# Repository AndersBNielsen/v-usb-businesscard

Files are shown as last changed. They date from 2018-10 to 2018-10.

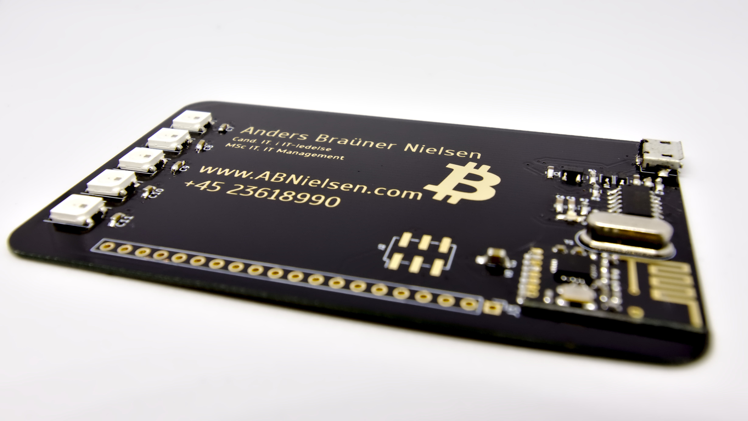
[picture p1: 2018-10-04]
abnielsen-bcard.jpg

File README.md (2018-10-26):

# ATTiny84 V-USB Business card

Read the full description here: https://abnielsen.com/2018/10/02/business-card-rf24-ws2812b-attiny84-usb/

This project contains KiCad schematics and board layouts, modified versions of the RF24 nRF24L01+ library (https://github.com/nRF24/RF24) and Adafruit's TrinketHidCombo library (https://github.com/adafruit/Adafruit-Trinket-USB/tree/master/TrinketHidCombo) to work with the ATTiny84 with a 16mhz crystal. 

The TrinketHidCombo needed to be reconfigured for the different registers on the T84 compared to the T85 and the RF24 library needed to be made compatible with clockwise pin definitions(a la damellis core).

The microusb connector footprint used is a modified version of one found in Sparkfun's KiCAD connector library. Thanks! (https://github.com/sparkfun/SparkFun-KiCad-Libraries) 

## So what does it do?
It's my business card. It also doubles as a development board. It successfully fits code to accept commands wirelessly to control onboard(or external) WS2812B LEDs and send Play/Pause/Vol up/Vol down/Stop media keys via USB, into the 8192 bytes available on an ATTiny84. Hardware for sending the RF commands is not covered by this project. 

Update: It now also works as a USBasp programmer! (https://github.com/AndersBNielsen/USBasp-t)

My business card

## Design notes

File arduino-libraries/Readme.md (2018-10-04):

This folder contains the Arduino libraries used(if modified for this project).

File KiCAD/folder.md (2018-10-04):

This folder contains schematics and board layout for KiCAD (v4)
..and a Bitcoin logo

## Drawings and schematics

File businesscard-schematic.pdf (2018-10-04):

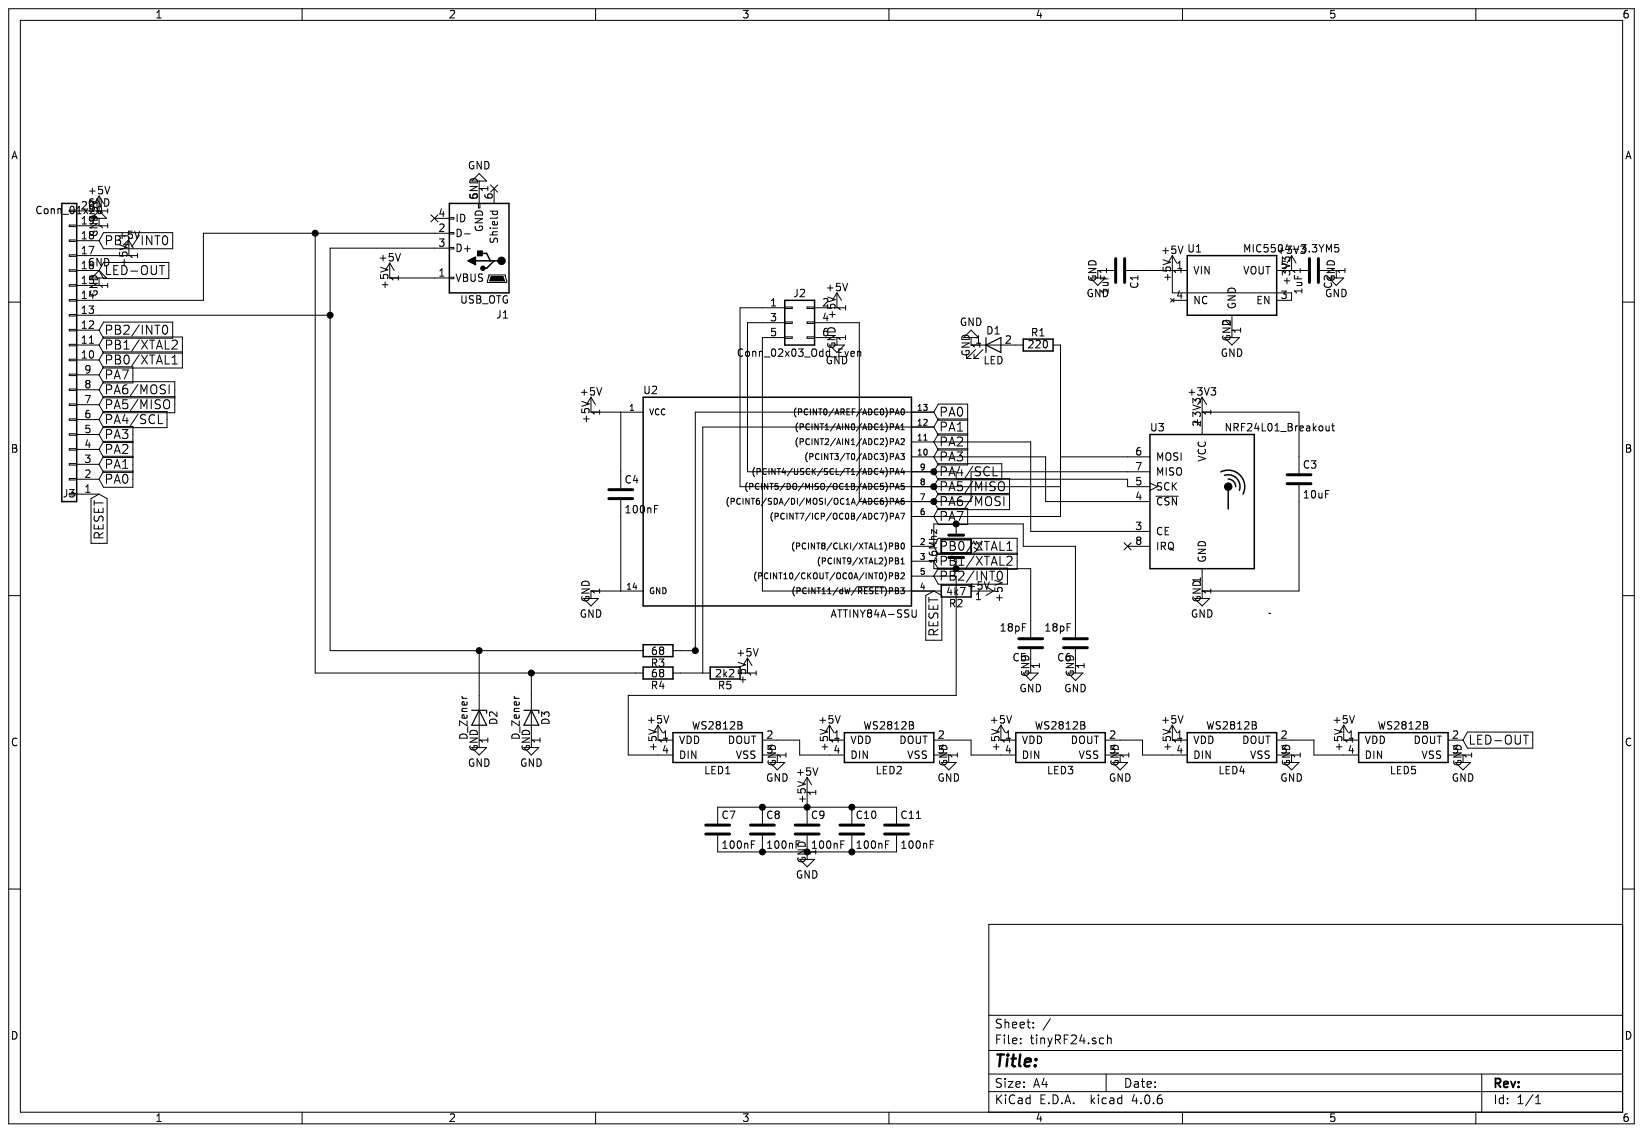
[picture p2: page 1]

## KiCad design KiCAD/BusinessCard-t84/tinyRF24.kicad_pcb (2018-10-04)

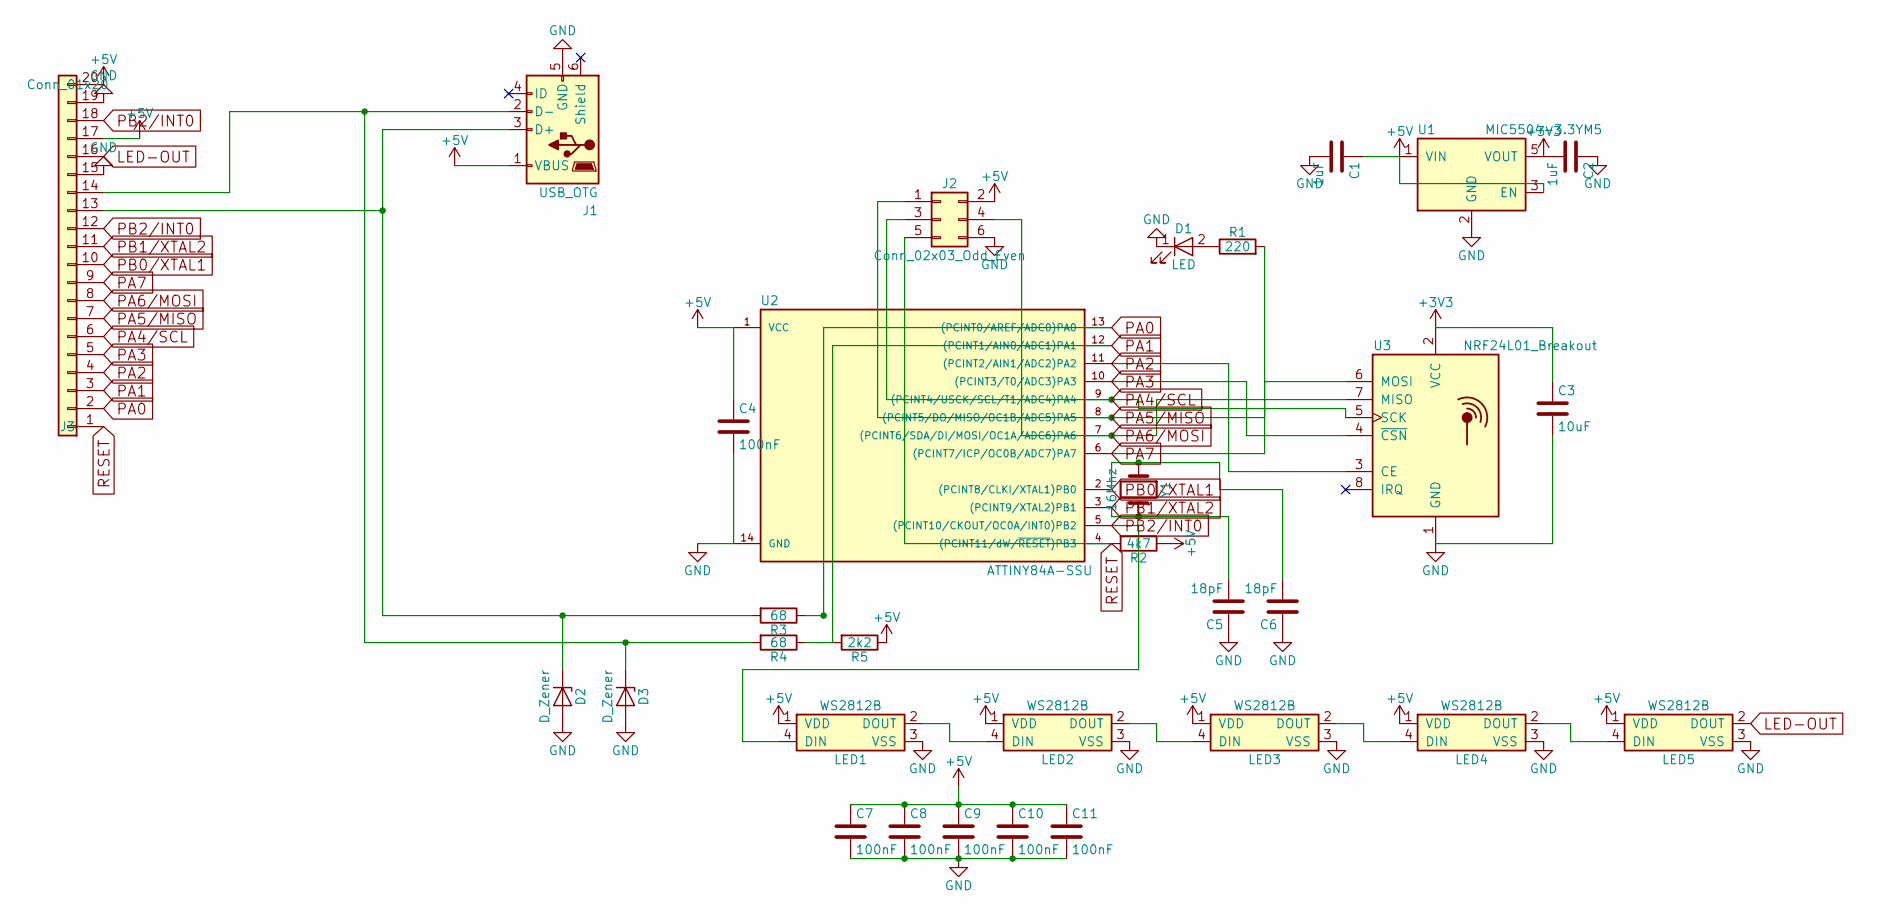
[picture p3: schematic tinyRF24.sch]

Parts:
C1, C2: 1uF; C_0603_HandSoldering
C3: 10uF; C_0805_HandSoldering
C4, C7, C8, C9, C10, C11: 100nF; C_0603_HandSoldering
C5, C6: 18pF; C_0603_HandSoldering
D1: LED; LED_0603_HandSoldering
D2, D3: D_Zener; D_SOD-323
J1: USB_OTG; USB-B-MICRO-SMD_V03-fixed
J2: Conn_02x03_Odd_Even; Pin_Header_Straight_2x03_Pitch2.54mm_SMD
J3: Conn_01x20; Pin_Header_Straight_1x20_Pitch2.54mm
LED1, LED2, LED3, LED4, LED5: WS2812B; LED_WS2812B-PLCC4
R1: 220; R_0603_HandSoldering
R2: 4k7; R_0603_HandSoldering
R3, R4: 68; R_0603_HandSoldering
R5: 2k2; R_0603_HandSoldering
U1: MIC5504-3.3YM5; SOT-23-5
U2: ATTINY84A-SSU; SOIC-14_3.9x8.7mm_Pitch1.27mm
U3: NRF24L01_Breakout; NRF24L01-SMD
Y1: 16Mhz; Crystal_HC49-4H_Vertical

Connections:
+3V3: C2.2, C3.1, U1.5 (VOUT), U3.2 (VCC)
+5V: C1.1, C4.1, C7.1, C8.1, C9.1, C10.1, C11.1, J1.1 (VBUS), J2.2, J3.17, J3.20, LED1.1 (VDD), LED2.1 (VDD), LED3.1 (VDD), LED4.1 (VDD), LED5.1 (VDD), R2.1, R5.1, U1.1 (VIN), U1.3 (EN), U2.1 (VCC)
GND: C1.2, C2.1, C3.2, C4.2, C5.1, C6.1, C7.2, C8.2, C9.2, C10.2, C11.2, D1.1 (K), D2.2 (A), D3.2 (A), J1.5 (GND), J2.6, J3.15, J3.19, LED1.3 (VSS), LED2.3 (VSS), LED3.3 (VSS), LED4.3 (VSS), LED5.3 (VSS), U1.2 (GND), U2.14 (GND), U3.1 (GND)
LED-OUT: J3.16, LED5.2 (DOUT)
unnamed: D1.2 (A), R1.1
unnamed: D2.1 (K), J1.3 (D+), J3.13, R3.2
unnamed: D3.1 (K), J1.2 (D-), J3.14, R4.2
unnamed: LED1.2 (DOUT), LED2.4 (DIN)
unnamed: LED2.2 (DOUT), LED3.4 (DIN)
unnamed: LED3.2 (DOUT), LED4.4 (DIN)
unnamed: LED4.2 (DOUT), LED5.4 (DIN)
PA0: J3.2, R3.1, U2.13 ((PCINT0/AREF/ADC0)PA0)
PA1: J3.3, R4.1, R5.2, U2.12 ((PCINT1/AIN0/ADC1)PA1)
PA2: J3.4, U2.11 ((PCINT2/AIN1/ADC2)PA2), U3.3 (CE)
PA3: J3.5, U2.10 ((PCINT3/T0/ADC3)PA3), U3.4 (~CSN)
PA4/SCL: J2.3, J3.6, U2.9 ((PCINT4/USCK/SCL/T1/ADC4)PA4), U3.5 (SCK)
PA5/MISO: J2.1, J3.7, U2.8 ((PCINT5/DO/MISO/OC1B/ADC5)PA5), U3.6 (MOSI)
PA6/MOSI: J2.4, J3.8, U2.7 ((PCINT6/SDA/DI/MOSI/OC1A/ADC6)PA6), U3.7 (MISO)
PA7: J3.9, R1.2, U2.6 ((PCINT7/ICP/OC0B/ADC7)PA7)
PB0/XTAL1: C6.2, J3.10, U2.2 ((PCINT8/CLKI/XTAL1)PB0), Y1.1
PB1/XTAL2: C5.2, J3.11, U2.3 ((PCINT9/XTAL2)PB1), Y1.2
PB2/INT0: J3.12, J3.18, LED1.4 (DIN), U2.5 ((PCINT10/CKOUT/OC0A/INT0)PB2)
RESET: J2.5, J3.1, R2.2, U2.4 ((PCINT11/dW/~RESET~)PB3)

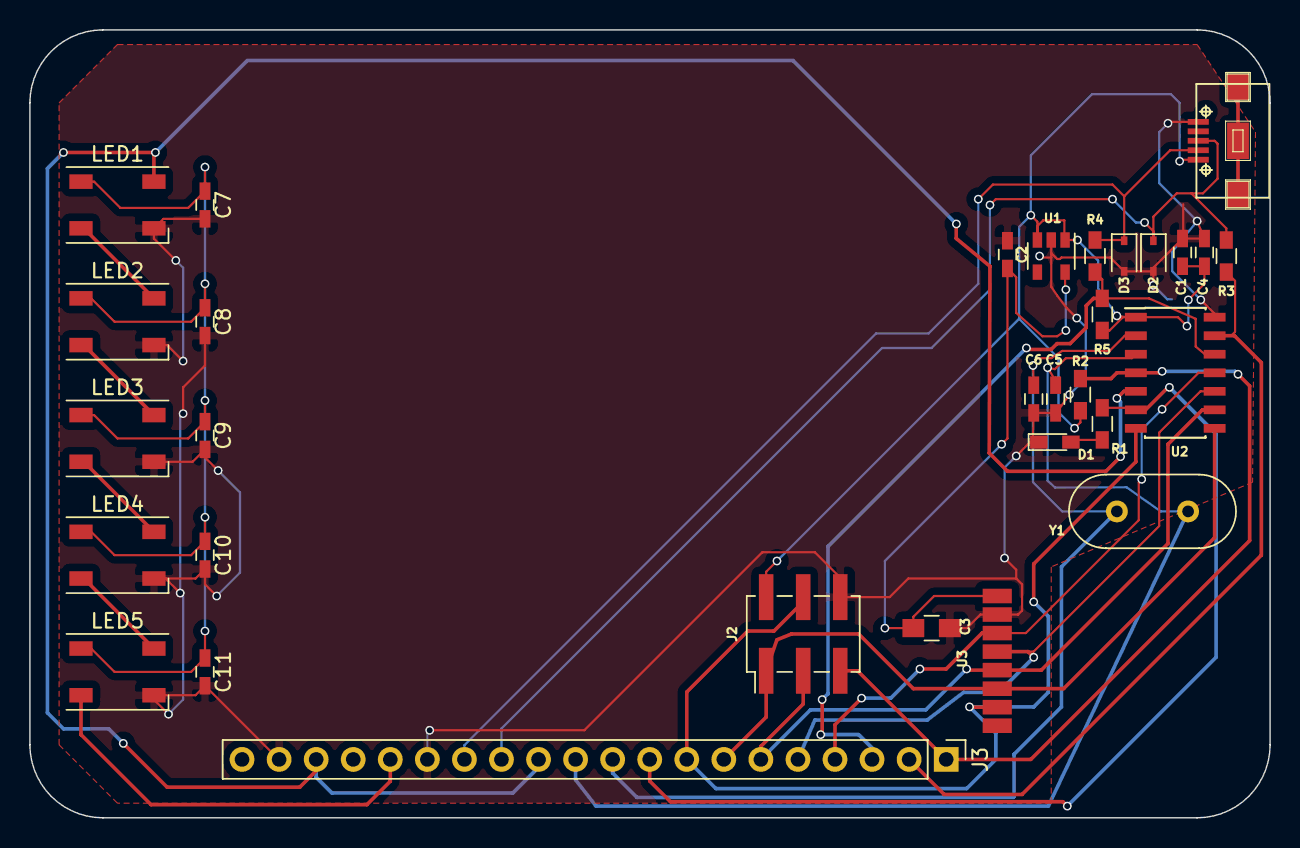
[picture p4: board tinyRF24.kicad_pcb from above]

Board: 2 copper layers, 85.0 x 54.0 mm, 31 parts (0 on the bottom side), 23 nets.

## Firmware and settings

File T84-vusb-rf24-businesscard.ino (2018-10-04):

#include <RF24.h> //My fork with a fix for ATTiny44/84
#include <avr/wdt.h>
#include <avr/interrupt.h>
#include <Adafruit_NeoPixel.h>
#ifdef __AVR__
  #include <avr/power.h>
#endif

#define BIT(x) (0x01 << (x)) 
#define getBit(p,m) ((p) & BIT((m)))

#include <TrinketHidCombo.h> //My fork for ATTiny44/84

#define PIN 8
Adafruit_NeoPixel strip = Adafruit_NeoPixel(5, PIN, NEO_GRB + NEO_KHZ800);

#define LED_BUILTIN 7

uint8_t ledState = HIGH; //Status LED
unsigned long previousMillis = 0;
unsigned int freq = 1000; //LED blinking frequency
uint8_t mode = 1;
uint8_t isConnected;

//uint64_t pipe01 = 0xFAFBFCFDFELL;
uint64_t pipe02 = 0xFAFAFAFA02LL;
RF24 radio(2, 3);

typedef struct{
  byte mode;
  byte data;
  uint64_t address;
}
message;

message msg; 

void setup() {

pinMode(LED_BUILTIN, OUTPUT);
 
TrinketHidCombo.begin();
while (getBit(PORTA,7) == 0 && millis() < 2000) { //I hackish-ly set A7 high in usbdrv.c / usbDeviceRead(), since TrinkedHidCombo.isConnected() doesnt work for some reason.
stayAliveDelay(0);
}
if (millis() < 1999) { //If under 2 sec then we have USB.
  isConnected = 1;
  mode = 3; 
}

strip.begin();
//  strip.show(); // Initialize all pixels to 'off' //Scraping a few bytes
    
  radio.begin();
   radio.setPayloadSize(sizeof(msg));
   
//Error out if radio not detected 
#ifdef debug 
  if (!radio.isPVariant()) { //Easy way to detect if tranceiver correctly connected
  while (1) {
    digitalWrite(LED_BUILTIN, HIGH);
    delay(50);
    digitalWrite(LED_BUILTIN, LOW);
    delay(50);
  }
}
#endif

//Send out address for any remote to pick up when first powered on
#ifdef debug
 radio.stopListening();
  radio.setPayloadSize(sizeof(msg));
  radio.openWritingPipe(pipe01);
  msg.address = pipe02;
  msg.data = 100;
  msg.mode = 100;
bool ok = radio.write(&msg, sizeof(msg)); 
#endif
//Maybe do something if successfully sent.


//  radio.openReadingPipe(0, pipe01);
  radio.openReadingPipe(1, pipe02);
  radio.startListening();

  wdt_enable(WDTO_2S);// enable 2s watchdog timer
  WDTCSR &= ~(1<<WDE);
  WDTCSR |= (1<<WDIE);
    wdt_reset();
}

void loop() {
uint8_t pipe;
stayAliveDelay(0);

 if (radio.available(&pipe)) //Msg available?
  {
     while (radio.available()) {     
       radio.read(&msg, sizeof(msg)); //Get message
     }
  
//Parse message
    switch (msg.data) {
        case 1:
        mode = 1;
        if (isConnected) TrinketHidCombo.pressMultimediaKey(MMKEY_PLAYPAUSE);
        break;
        case 2:
        mode = 2;
        if (isConnected) TrinketHidCombo.pressMultimediaKey(MMKEY_VOL_UP);
        break;
        case 3:
        mode = 3;
        if (isConnected) TrinketHidCombo.pressMultimediaKey(MMKEY_VOL_DOWN);
        break;
        case 4:
        mode = 4;
        if (isConnected) TrinketHidCombo.pressMultimediaKey(MMKEY_STOP);
        break;
        default:
       freq = 0;
 break;
    }
  }
switch (mode) {
              
        case 1:
        rainbow(10);        
        break;
        case 2:
        rainbowCycle(10);
        break;
        case 3:
        //Set to princess's color
        for(int i=0; i<strip.numPixels(); i++) {
          if (radio.available()) break;
        strip.setPixelColor(i, 255,0,255);
        }
        break;
        case 4:
        //Off
        for(int i=0; i<strip.numPixels(); i++) {        
        strip.setPixelColor(i, 0,0,0);
        if (radio.available()) break;
        freq = 0;
        }  
        default:
       freq = 0;
 break;
    }
    strip.show();
//Non-blocking blinking
  if (millis() - previousMillis >= freq) {
    // save the last time you blinked the LED
    previousMillis = millis();

    // if the LED is off turn it on and vice-versa:
      if (ledState == LOW && freq > 0) {
        ledState = HIGH;
      } else {
        ledState = LOW;
      }
    // set the LED with the ledState of the variable:
    digitalWrite(LED_BUILTIN, ledState);
  }


}

// Fill the dots one after the other with a color
void colorWipe(uint32_t c, uint8_t wait) {
  for(uint16_t i=0; i<strip.numPixels(); i++) {
    if (radio.available()) break;
    strip.setPixelColor(i, c);
    strip.show();
    stayAliveDelay(wait);
  }
}

void rainbow(uint8_t wait) {
  uint16_t i, j;

  for(j=0; j<256; j++) {
    if (radio.available()) break;
    for(i=0; i<strip.numPixels(); i++) {
      if (radio.available()) break;
      strip.setPixelColor(i, Wheel((i+j) & 255));
    }
    strip.show();
    stayAliveDelay(wait);
  }
}

// Slightly different, this makes the rainbow equally distributed throughout
void rainbowCycle(uint8_t wait) {
  uint16_t i, j;

  for(j=0; j<256*5; j++) { // 5 cycles of all colors on wheel
    if (radio.available()) break;
    for(i=0; i< strip.numPixels(); i++) {
      if (radio.available()) break;
      strip.setPixelColor(i, Wheel(((i * 256 / strip.numPixels()) + j) & 255));
    }
    strip.show();
    stayAliveDelay(wait);
  }
}

// Input a value 0 to 255 to get a color value.
// The colours are a transition r - g - b - back to r.
uint32_t Wheel(byte WheelPos) {
  WheelPos = 255 - WheelPos;
  if(WheelPos < 85) {
    return strip.Color(255 - WheelPos * 3, 0, WheelPos * 3);
  }
  if(WheelPos < 170) {
    WheelPos -= 85;
    return strip.Color(0, WheelPos * 3, 255 - WheelPos * 3);
  }
  WheelPos -= 170;
  return strip.Color(WheelPos * 3, 255 - WheelPos * 3, 0);
}

void stayAliveDelay (long datime) {
  TrinketHidCombo.poll();
    wdt_reset();
  long starttime = millis();
  while (millis() - starttime < datime) {
    TrinketHidCombo.poll();
    wdt_reset();
  }
}

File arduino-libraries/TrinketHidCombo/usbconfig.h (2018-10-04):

/* Name: usbconfig.h
 * Project: V-USB, virtual USB port for Atmel's(r) AVR(r) microcontrollers
 * Author: Christian Starkjohann
 * Creation Date: 2005-04-01
 * Tabsize: 4
 * Copyright: (c) 2005 by OBJECTIVE DEVELOPMENT Software GmbH
 * License: GNU GPL v2 (see License.txt), GNU GPL v3 or proprietary (CommercialLicense.txt)
 */

/*
This file has been modified for use as a part of TrinketHidCombo

Copyright (c) 2013 Adafruit Industries
All rights reserved.

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
You should have received a copy of the GNU Lesser General Public
License along with TrinketHidCombo. If not, see
<http://www.gnu.org/licenses/>.
*/

#include "cmdline_defs.h"

#ifndef __usbconfig_h_included__
#define __usbconfig_h_included__

/* ---------------------------- Hardware Config ---------------------------- */

#if defined (__AVR_ATtiny44__) || defined (__AVR_ATtiny84__)
#define USB_CFG_IOPORTNAME      A
#define USB_CFG_DMINUS_BIT      1
#define USB_CFG_DPLUS_BIT       0
#endif
//#define USB_CFG_IOPORTNAME      B
/* This is the port where the USB bus is connected. When you configure it to
 * "B", the registers PORTB, PINB and DDRB will be used.
 */
//#define USB_CFG_DMINUS_BIT      3
/* This is the bit number in USB_CFG_IOPORT where the USB D- line is connected.
 * This may be any bit in the port.
 */
//#define USB_CFG_DPLUS_BIT       4
/* This is the bit number in USB_CFG_IOPORT where the USB D+ line is connected.
 * This may be any bit in the port. Please note that D+ must also be connected
 * to interrupt pin INT0! [You can also use other interrupts, see section
 * "Optional MCU Description" below, or you can connect D- to the interrupt, as
 * it is required if you use the USB_COUNT_SOF feature. If you use D- for the
 * interrupt, the USB interrupt will also be triggered at Start-Of-Frame
 * markers every millisecond.]
 */
#define USB_CFG_CLOCK_KHZ       (F_CPU/1000)
/* Clock rate of the AVR in kHz. Legal values are 12000, 12800, 15000, 16000,
 * 16500, 18000 and 20000. The 12.8 MHz and 16.5 MHz versions of the code
 * require no crystal, they tolerate +/- 1% deviation from the nominal
 * frequency. All other rates require a precision of 2000 ppm and thus a
 * crystal!
 * Since F_CPU should be defined to your actual clock rate anyway, you should
 * not need to modify this setting.
 */
#define USB_CFG_CHECK_CRC       0
/* Define this to 1 if you want that the driver checks integrity of incoming
 * data packets (CRC checks). CRC checks cost quite a bit of code size and are
 * currently only available for 18 MHz crystal clock. You must choose
 * USB_CFG_CLOCK_KHZ = 18000 if you enable this option.
 */

/* ----------------------- Optional Hardware Config ------------------------ */

/* #define USB_CFG_PULLUP_IOPORTNAME   D */
/* If you connect the 1.5k pullup resistor from D- to a port pin instead of
 * V+, you can connect and disconnect the device from firmware by calling
 * the macros usbDeviceConnect() and usbDeviceDisconnect() (see usbdrv.h).
 * This constant defines the port on which the pullup resistor is connected.
 */
/* #define USB_CFG_PULLUP_BIT          4 */
/* This constant defines the bit number in USB_CFG_PULLUP_IOPORT (defined
 * above) where the 1.5k pullup resistor is connected. See description
 * above for details.
 */

/* --------------------------- Functional Range ---------------------------- */
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

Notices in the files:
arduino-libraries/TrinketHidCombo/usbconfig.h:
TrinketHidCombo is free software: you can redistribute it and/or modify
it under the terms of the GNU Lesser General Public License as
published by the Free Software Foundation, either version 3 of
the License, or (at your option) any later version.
